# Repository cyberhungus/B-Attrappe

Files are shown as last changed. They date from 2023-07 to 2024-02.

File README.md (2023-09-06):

# B-Attrappe
## Brief
Software for a combined timing- and media playback device used in an Escape Room. All following documentation is written in German. 

## Funktionsübersicht

Die Spielleitung kann mit einem Drehimpulsgeber zwischen 3 Spielzeiten wählen. 

Hierfür wird ein Menü auf dem OLED angezeigt. 

Das Symbol ">" zeigt an, welche Zeit ausgewählt ist. 

Mit dem Knopf des Drehimpulsgebers wird das Spiel gestartet. 

Alternativ kann das Spiel mit dem Intro-Knopf gestartet werden. 

Dieser erlaubt den Teilnehmenden weiterhin, jederzeit eine Intro-Nachricht mit dem DFplayer abzuspielen. 

Wird das Spiel gestartet, zeigt der OLED die verbleibende Spielzeit an. 

Während des Spiels kann mit dem Drehimpulsgeber die Lautstärke des DFplayer manipuliert werden.

Die Teilnehmenden müssen herausfinden, welches der vier Kabel zertrennt werden muss, um das Gerät zu entschärfen. 

Wird das korrekte Kabel gekappt, wird eine Gratulationsnachricht abgespielt. 

Läuft die Zeit ab, oder wird das falsche Kabel gekappt, wird ein Explosionsgeräusch abgespielt.

Wenn das Spiel gewonnen oder verloren wird, kann das Gerät mit den Knöpfen (Intro oder Encoder) resettet werden. 

Das Gerät prüft vor Spielstart, ob alle Kabel korrekt verbunden sind - ansonsten wird das Spiel nicht gestartet, um Fehlern vorzubeugen. 

## Vorbereitung 
Alle Kabel vom rechten grünen Schraubterminal müssen mit dem linken grünen Schraubterminal verbunden werden. 

Andernfalls wird der Start des Timers verhindert. 

Die Reihenfolge der Verbindungen links ist hierbei unerheblich. 

Das äußere rechte Schraubterminal (Siehe Platinenübersicht in diesem Dokument) ist für das Deaktivierungskabel vorgesehen. 

An dieser Stelle sollte ein zum Spielfluss passendes Kabel (BLAU) verwendet werden. 

Die Farbgebung der anderen Kabel kann nach Gutdünken erfolgen.

Die Mikro-SD Karte muss präpariert werden, indem drei Ordner mit den Namen "01", "02", "03" erstellt werden. 

In diesen Ordnern ist jeweils eine Datei im mp3-Format abzuspeichern. 

Diese muss den Dateinamen "0001.mp3" erhalten. 

#### Achtung: Wird zur Vorbereitung der SD-Karte ein MAC oder Linux Computer benutzt, sind eventuell zusätzliche Schritte zu befolgen. Diese sind der DFPlayer-Dokumentation zu enehmen. Wir empfehlen die Verwendung eines Windows-Systems!

Der Abspielzeitpunkt der MP3-Dateien ist der folgenden Tabelle zu entnehmen. 

| Ordner | Abspielzeitpunkt |
|---|---|
| 01 | Intro |
| 02 | Game Over |
| 03 | Game Won |

## Verwendete Komponenten

| Komponente | Anzahl | Funktion | Optional? |
|---|---|---|---|
| Arduino Nano | 1 | Microcontroller (es können andere Microcontroller verwendet werden) | |
| DFPlayer Mini | 1 | Spielt MP3 von SD-Karte | |
| Drehimpulsgeber mit Button | 1 | User Input (versch. Funktionen) | |
| OLED-Screen 128x64 | 1 | User Output | |
| Knopf (Vandalismustaster) | 1 | Intro abspielen | |
| 1k Resistor | 2 | Noise reduzieren | |
| Dupont Pinheader 1x5 - male | 1 | Verbinden des Drehimpulsgebers | x |
| Dupont Pinheader 1x4 - male | 1 | Verbinden des OLED-Screens | x |
| Dupont Pinheader 1x2 - male | 2 | Verbinden des Introbuttons, Verbinden des Lautsprechers | x |
| Dupont Pinheader 1x8 - female | 2 | Verbinden des DFPlayer | x |
| Lochrasterplatine | 1 | Hält andere Komponenten | x |
| Schraubterminals 5.08mm Grün 1x2er | 4 | Verbinden der zerschneidbaren Kabel - zu 2x4er zusammenstecken | x |
| Micro SD-Karte | 1 | Enthält Dateien zum Abspielen mit DFPlayer - Größe egal, muss nur 3 MP3s halten | |
| Lautsprecher | 1 | Macht Geräusche | |
## Verbindungen Arduino

| Pin Arduino Nano  | Pin andere Komponente | Notizen |
|---|---|---|
| 5V | OLED-Pinheader (OLED-VCC) | |
| 5V | Drehimpulsgeber Pinheader (Drehimpulsgeber +) | |
| 5V | DFPlayer VCC | |
| GND | OLED-Pinheader (OLED-GND) | |
| GND | Drehimpulsgeber Pinheader (Drehimpulsgeber GND) | |
| GND | Introbutton Pinheader | (Polarität egal) |
| GND | Kabel Schraubterminal Links | |
| GND | DFPlayer GND | |
| A4 | OLED-Pinheader (SDA) | Hardware i2c - nicht änderbar |
| A5 | OLED-Pinheader (SCL) | Hardware i2c - nicht änderbar |
| D11 | DFPlayer RX (via 1k Resistor) | 1k Resistor unterdrückt Noise |
| D12 | DFPlayer TX (via 1k Resistor) | 1k Resistor unterdrückt Noise |
| D10 | Drehimpulsgeber Pinheader (Drehimpulsgeber SW)  | Button des Impulsgebers |
| D2 | Drehimpulsgeber Pinheader (Drehimpulsgeber CLK) | D2 unterstützt Interrupts - nicht ändern |
| D3 | Drehimpulsgeber Pinheader (Drehimpulsgeber DT)  | D3 unterstützt Interrupts - nicht ändern |
| D5 | Introbutton Pinheader | Eingang des Introbuttons (Polarität egal) |
| D9, D8, D7 | Kabel Schraubterminal Rechts | Eingänge für falsche Kabel |
| D6 | Kabel Schraubterminal Rechts | Eingang Deaktivierungskabel |

## Andere Verbindungen

| Verbindung A | Verbindung B | Notiz |
|---|---|---|
| DFPlayer SPK_1 | Pinheader Lautsprecher | Bei Lautsprecher ist Polarität egal |
| DFPlayer SPK_2 | Pinheader Lautsprecher | Bei Lautsprecher ist Polarität egal |

## Ablaufplan


## Platinenübersicht


## Platinenübersicht Alternativ

Die 2 gebauten Platinen weichen leicht voneinander ab. 
Dies ist die Übersicht der kleineren Platine.
Durch einen Lötfehler sind hier Pin 11 und 12 vertauscht. 



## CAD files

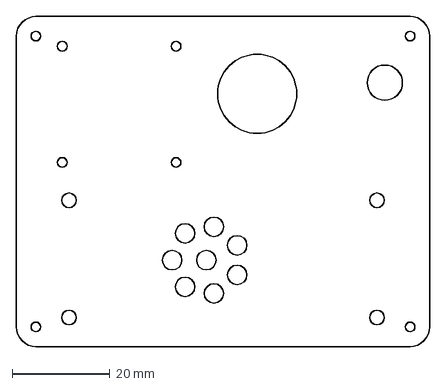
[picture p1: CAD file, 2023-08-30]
Battrappe Laser Glass.dxf
84.6 x 67.6 mm

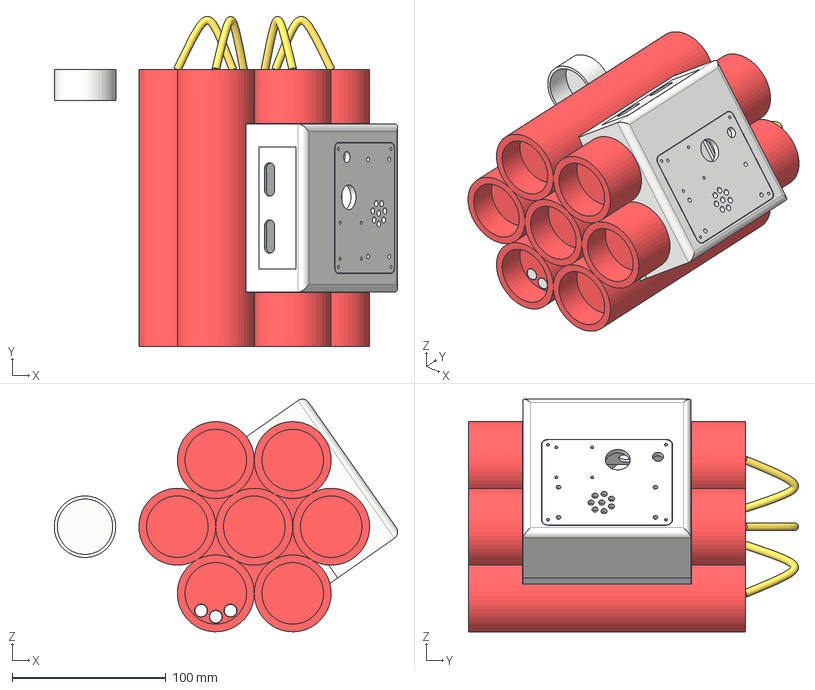
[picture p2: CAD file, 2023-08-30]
Battrappe v7.step
223.2 x 214.4 x 151.2 mm
Nobel
Lower
Midle
GlassFront
LowerLid
Cabel
SteelRod
CenterPlug
BlindPlug

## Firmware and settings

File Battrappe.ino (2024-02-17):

//Libraries für OLED
#include <SPI.h>
#include <Wire.h>

//library für dfplayer mini
#include "Arduino.h"
#include "SoftwareSerial.h"
#include "DFRobotDFPlayerMini.h"
#include <U8g2lib.h>

//erstelle dfplayer objekt und softwareSerial
SoftwareSerial mySoftwareSerial(11,12  ); // RX, TX
DFRobotDFPlayerMini myDFPlayer;
void printDetail(uint8_t type, int value);

//Pin zum auslesen des EncoderButtons
const int encoderButtonPin = 10;
//Pin zum auslesen des EncoderButtons
const int introButtonPin = 5;
// Rotary Encoder Inputs
const int CLK = 2;
const int DT  = 3;

//variablen für den Encoder
int counter = 0;
int currentStateCLK;
int lastStateCLK;

//fake kabel pins
int fakeCables[] = {9, 8, 7};
int fakeCablesLength = 3;
//deaktivierungskabel pins
int deactivateCable = 6;


//welche Minutenwerte stehen zur auswahl?
int minuteValues[] = {30, 45, 60, 1};
//Wie viele minutenwerte sind es?
int minuteValuesLength = 4;
//welcher minutenwert ist gerade ausgewählt?
int currentSelection = 0;
//wurde der timer gestartet?
bool timerStarted = false;
//wenn der timer gestartet wurde enthalt diese variable die endzeit. in millisekunden
long endTime = 0 ;

//ist das spiel gewonnen oder verloren
bool gameOverState = false;
bool gameWonState = false;
//hält die volume
int vol = 30;
//wurde die Vol vor kurzem verändert, soll ein spezieller screen gezeigt werden
bool volChanged = false;
// wann endet die anzeige der time anzeige
long volChangeEnd;
//wie lange wird die volchange message gezeigt
int volChangeDur = 1500;

//instanziiere objekt für display
U8G2_SSD1306_128X64_NONAME_1_SW_I2C u8g2(U8G2_R0, /* clock=*/ SCL, /* data=*/ SDA, /* reset=*/ U8X8_PIN_NONE);   // All Boards without Reset of the Display





//wenn alle kabel korrekt verbunden sind, ist cablestate true, sonst false
bool cableState = true;


void setup() {

  Serial.begin(115200);
  Serial.println("B-Attrappe von MM 2023");

  u8g2.begin();

  pinMode(encoderButtonPin, INPUT_PULLUP);
  pinMode(introButtonPin, INPUT_PULLUP);

  for (int i = 0; i < fakeCablesLength; i++) {
    pinMode(fakeCables[i], INPUT_PULLUP);
  }
  pinMode(deactivateCable, INPUT_PULLUP);


  pinMode(CLK, INPUT);
  pinMode(DT, INPUT);
  lastStateCLK = digitalRead(CLK);

  attachInterrupt(digitalPinToInterrupt(2), updateEncoder, CHANGE);
  attachInterrupt(digitalPinToInterrupt(3), updateEncoder, CHANGE);

  //starte softwareserial und dfplayer
  mySoftwareSerial.begin(9600);
  if (!myDFPlayer.begin(mySoftwareSerial)) {
    //halte system an wenn dfplayer nicht findbar
    Serial.println("DFPLAYER error");
    //zeige infos dazu auf dem screen
    showDFPlayerError();
    while (1);
  }
  Serial.println(F("DFPlayer Mini online."));

  myDFPlayer.volume(vol);





}
long oldPosition  = -999;

void loop() {
  //zeige sachen auf dem Display an
  readButtons();

  //Prüfe werte des Drehimpulsgebers
  readEncoder();
  //schaue ob ein knopf gedrückt wurde
  readButtons();
  //gucke, welche zeitbasierten funktionen
  checkTimes();
  //prüfe ob die kabel durchgeschnitten wurden
  checkCables();
  readButtons();
    //Prüfe werte des Drehimpulsgebers
  readEncoder();
  u8g2.firstPage();
  do {
    showDisplay();
  } while (u8g2.nextPage());
  readButtons();
    //Prüfe werte des Drehimpulsgebers
  readEncoder();

}

//guckt ob alle kabel verbunden sind bzw welche kabel nicht verbunden sind
void checkCables () {

  //Cablestate wird true oder false, je nachdem ob alle kabel verbunden sind
  //wir machen das hier, damit das hauptmenü anzeigen kann ob das system bereit ist
  cableState = allCablesConnected();

  int cableres;
  //checke jedes fake kabel
  for (int i = 0; i < fakeCablesLength; i++) {
    //lese den pin
    cableres = digitalRead(fakeCables[i]);
    //wenn fake-kabel durchtrennt dann game over
    if (cableres == HIGH) {
      if (timerStarted) {
        gameOver();
        Serial.println("Fake cable severed");

      }
    }
  }
  //checke deaktivierungskabel
  cableres = digitalRead(deactivateCable);
  //wenn deaktivierungskabel getrennt dann gewonnen
  if (cableres == HIGH) {
    if (timerStarted) {
      gameWon();
      Serial.println("Correct cable severed");

    }
  }

}

//gibt wahr zurück, wenn alle kabel verbunden sind
//gibt falsch zurück, wenn nicht alle kabel verbunden
bool allCablesConnected() {
  int checksum = 0;
  int result = 0;
  //checke jedes fake kabel
  for (int i = 0; i < fakeCablesLength; i++) {
    //lese den pin
    result = digitalRead(fakeCables[i]);

    Serial.print("Fake at: ");
    Serial.print(fakeCables[i]);
    Serial.print(" - ");
    Serial.println(result);
    if (result == HIGH) {
      
        checksum++;
      
    }
  }
  //checke deaktivierungskabel
  result = digitalRead(deactivateCable);
  Serial.print("Real  at: ");
  Serial.print(deactivateCable);
  Serial.print(" - ");
  Serial.println(result);
  if (result == HIGH) {
    
      checksum++;
    
  }
  if (checksum != 0) {

    return false;
  }
  else {
    return true;
  }
}



void readEncoder() {

  //leseEncoder
  long newPosition = counter;

  //wenn position anders.
  if (newPosition != oldPosition) {
    //wenn kleiner als letze
    if (newPosition < oldPosition) {
      Serial.println("Kleiner");
      //wenn timer gestarted inkrementiere currentselection - wählt menüitems aus
      if (!timerStarted) {
        currentSelection++;
      }
      //wenn timer schon gestartet kann der encoder als lautstärkeregler verwendet werden
 
    }
    //wenn position größer als letze
    else if (newPosition > oldPosition) {
      Serial.println("grosser");
      //wenn timer gestartet dekrementiere currentselection - wählt menüitems aus
      if (!timerStarted) {
        currentSelection--;
      }
      //veringere Lautstärke

    }
  }
  //limitiere werte die currentselection annehmen kann
  if (currentSelection < 0) {
    currentSelection = minuteValuesLength - 1;
  }
  else if (currentSelection >= minuteValuesLength) {
    currentSelection = 0;
  }
  oldPosition = newPosition;
}

//prüft verschiedene Zeiten
void checkTimes() {
  //als erstes die zeit holen - wir wollen millis nicht immer wieder abrufen
  long current = millis();
  //nur wenn spiel nicht vorüber
  if (!gameWonState && !gameOverState) {
    //wenn timer gestarted, prüfe ob zeit abgelaufen
    if (timerStarted) {
      //wenn zeit jetzt größer als endzeit dann ist game over
      if (current > endTime) {
        Serial.println("Zeit abgelaufen!");
        gameOver();
      }
    }
  }

  if (volChanged) {
    if (current > volChangeEnd) {
      Serial.println("Ende der Volume Anzeige");
      volChanged = false;

    }


  }
}
//erhöht lautstärke
void increaseVol() {
  if (vol < 30) {

    vol++;
    myDFPlayer.volume(vol);
    volChanged = true;
    volChangeEnd = millis() + volChangeDur;
    Serial.print("Lautstarke geandert: " );
    Serial.println(vol);

  }
}
//verringert lautstärke
void decreaseVol() {
  if (vol > 5) {
    vol--;
    myDFPlayer.volume(vol);
    volChanged = true;
    volChangeEnd = millis() + volChangeDur;
    Serial.print("Lautstarke geandert: " );
    Serial.println(vol);
  }
}

//aufgerufen wenn falsches kabel getrennt oder zeit abgelaufen
void gameOver() {
  if (!gameOverState && !gameWonState) {
    //  fillcircle();
    gameOverState = true;
    playBoom();
    Serial.println("game over");
  }
}
//aufgerufen wenn korrektes kabel getrennt
void gameWon() {
  if (!gameOverState && !gameWonState) {
    gameWonState = true;
    playFanfare();
    Serial.println("game won");
  }
}

//diese funktion reagiert auf drücken des encoders oder des intro buttons
void readButtons() {
  //Intro Button Result
  int introRes = digitalRead(introButtonPin);

  //encoder Button result
  int encRes = digitalRead(encoderButtonPin);
  long timestamp = millis();

  //    Serial.print("EncoderButton:");
  //    Serial.println(encRes);
  //      Serial.print("Intro:");
  //    Serial.println(introRes);
  if (!gameOverState && !gameWonState) {

    //nur button eingaben akkzeptieren wenn wenn timer gestartet und alle Kabel korrekt verbunden
    if (!timerStarted && cableState) {
      //eingabe zum timer start mit dem encoder-knopf
      if (encRes == LOW) {
        showIntroInfo();
        delay(10);
        playIntro();
        delay(35000);
        playCountdown();
        delay(2000);
        timerStarted = true;
        timestamp = millis();
        endTime = timestamp + (minuteValues[currentSelection] * 60000);
        Serial.print("Timer gestartet um: ");
        Serial.print(timestamp);
        Serial.print(". Timer gestartet mit: ");
        Serial.print( minuteValues[currentSelection] );
        Serial.print("Ende: ");
        Serial.println(endTime);

      }
      //eingabe zum timer start mit dem Intro knopf
      if (introRes == LOW) {
        showIntroInfo();
        delay(10);
        playIntro();
        delay(35000);
        playCountdown();
        delay(2000);
        timestamp = millis();
        timerStarted = true;
        endTime = timestamp + (minuteValues[currentSelection] * 60000);
        Serial.print("Timer + Intro abspielen gestartet um: ");
        Serial.print(timestamp);


      }
    }
    else if (timerStarted) {
      //wenn timer schon läuft spielt der intro knopf nur das intro
      if (introRes == LOW) {
        Serial.print(" Intro abspielen gestartet um: ");
        Serial.print(timestamp);
        Serial.print("Ende: ");
        Serial.println(endTime);
        playIntro();
      }
    }
  }
  //wenn gameover oder gamewon resetten wir die variablen dafür, und somit das system
  else {
    if (encRes == LOW) {
      gameOverState = false;
      gameWonState = false;
      timerStarted = false;
      Serial.println("reset");
      showReset();
      delay(2000);
    }

    if (introRes == LOW) {

      gameOverState = false;
      gameWonState = false;
      timerStarted = false;
      Serial.println("reset");
      showReset();
      delay(2000);
    }
  }
}

//diese funktion regelt die anzeige auf dem Bildschirm
void showDisplay() {
  //zeige splashscreen wenn system gestartet wird
  if (millis() < 3000) {
    showSplash();
  } else {
    //wenn das spiel nicht im gamover oder gewon zustand ist
    if (!gameOverState && !gameWonState) {
      //wenn der timer nicht gestartet ist, zeige hauptmenü
      if (!timerStarted) {
        //zeichne minutenwert optionen
        for (int i = 0; i < minuteValuesLength; i++) {

          u8g2.setFont(u8g2_font_ncenB10_tr);
          u8g2.setCursor(10, 20 + (i * 15));
          u8g2.print(minuteValues[i]);

        }
        //zeichne auswahlpfeil an der richtigen position, basierend auf der currentselection variabel
        u8g2.setCursor(0, 20 + ( currentSelection * 15));
        u8g2.print(">");

        //zeige an, ob die Kabel korrekt verbunden sind
        if (!cableState) {
          u8g2.setFont(u8g2_font_5x7_tr);

          u8g2.setCursor(40, 60 );
          u8g2.print("KABELFEHLER");
        }
        else {
          u8g2.setFont(u8g2_font_5x7_tr);

          u8g2.setCursor(40, 60 );
          u8g2.print("KABEL OKAY");
        }

      }
      //wenn der timer gestartet wurde, zeige die verbleibende zeit an
      else {
        if (!volChanged) {
          long remTime = endTime - millis();
          long remMinutes = remTime / 60000;
          long remSeconds = remTime / 1000 % 60;
          u8g2.setFont(u8g2_font_7Segments_26x42_mn);
          u8g2.setCursor(0, 42);
          u8g2.print(remMinutes);
          u8g2.setCursor(58, 42);
          u8g2.print(":");
          u8g2.setCursor(70, 42);
          u8g2.print(remSeconds);
        }
        //es sei denn, die lautstärke wurde kürzlich geändert: dann zeige lautstärke an
        else {
          u8g2.setFont(u8g2_font_ncenB10_tr);
          u8g2.drawStr(0, 20 ,  "VOL");
          u8g2.drawStr(64, 20 ,  String(vol).c_str());
        }
      }
    }
    //folgender Code zeigt informationen an, wenn spiel gewonnen oder verloren
    else if (gameOverState && !gameWonState) {
      u8g2.setFont(u8g2_font_ncenB10_tr);
      u8g2.drawStr(0, 30 , "Game Over");
      u8g2.setFont(u8g2_font_5x7_tr);
      u8g2.drawStr(0, 50 , "Knopf zum Reset ");
    }
    else if (gameWonState && !gameOverState) {
      u8g2.setFont(u8g2_font_ncenB10_tr);
      u8g2.drawStr(0, 20 , "GEWONNEN!");
      u8g2.setFont(u8g2_font_5x7_tr);
      u8g2.drawStr(0, 40 , "Saubere Arbeit!  ");
      u8g2.drawStr(0, 60 , "Knopf zum Reset ");
    }
    //wenn spiel gleichzeitig gewonnen und verloren ist, zeige ERROR an
    else if (gameWonState && gameOverState) {
      u8g2.setFont(u8g2_font_ncenB10_tr);
      u8g2.drawStr(0, 30 , "ERROR");
      u8g2.setFont(u8g2_font_5x7_tr);
      u8g2.drawStr(0, 50 , "Knopf zum Reset ");
    }





  }
}

//playfunktionen kapseln das abspielen bestimmter tracks auf dem DFPlayer
void playIntro() {
  myDFPlayer.playFolder(01, 01);
}
void playBoom() {
  myDFPlayer.playFolder(02, 01);
}
void playFanfare() {
  myDFPlayer.playFolder(03, 01);
}
void playCountdown() {
  myDFPlayer.playFolder(04, 01);
}

//diese funktion wird als callback aufgerufen, wenn der drehimpulsgeber bewegt wird
//sie regelt die interne logik des encoders
void updateEncoder() {
  // Read the current state of CLK
  currentStateCLK = digitalRead(CLK);

  // If last and current state of CLK are different, then pulse occurred
  // React to only 1 state change to avoid double count
  if (currentStateCLK != lastStateCLK  && currentStateCLK == 1) {

    // If the DT state is different than the CLK state then
    // the encoder is rotating CCW so decrement
    if (digitalRead(DT) != currentStateCLK) {
      counter --;

    } else {
      // Encoder is rotating CW so increment
      counter ++;

    }


    // Serial.print(" | Counter: ");
    //Serial.println(counter);
  }

  // Remember last CLK state
  lastStateCLK = currentStateCLK;
}
void showIntroInfo() {

  u8g2.setFont(u8g2_font_ncenB10_tr);
  u8g2.drawStr(0, 24, "Intro spielt!");
  u8g2.drawStr(0, 48, "Bitte warten!");
}
void showSplash() {

  u8g2.setFont(u8g2_font_ncenB10_tr);
  u8g2.drawStr(0, 24, "Bomb!");
  u8g2.drawStr(0, 48, "MM 2023");

}
void showReset() {

  u8g2.setFont(u8g2_font_ncenB10_tr);
  u8g2.drawStr(0, 24, "RESET!");
  u8g2.drawStr(0, 48, "MM 2023");
}

void showDFPlayerError() {
  u8g2.firstPage();
  do {
    u8g2.setFont(u8g2_font_ncenB10_tr);
    u8g2.drawStr(0, 20 , "ERROR");
    u8g2.setFont(u8g2_font_5x7_tr);
    u8g2.drawStr(0, 30 , "DFPlayer-Problem ");
    u8g2.drawStr(0, 50 , "Checke SDCard");
  } while (u8g2.nextPage());

}

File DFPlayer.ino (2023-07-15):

void printDetail(uint8_t type, int value) {
  switch (type) {
    case TimeOut:
      Serial.println(F("Time Out!"));
      break;
    case WrongStack:
      Serial.println(F("Stack Wrong!"));
      break;
    case DFPlayerCardInserted:
      Serial.println(F("Card Inserted!"));
      break;
    case DFPlayerCardRemoved:
      Serial.println(F("Card Removed!"));
      break;
    case DFPlayerCardOnline:
      Serial.println(F("Card Online!"));
      break;
    case DFPlayerUSBInserted:
      Serial.println("USB Inserted!");
      break;
    case DFPlayerUSBRemoved:
      Serial.println("USB Removed!");
      break;
    case DFPlayerPlayFinished:
      Serial.print(F("Number:"));
      Serial.print(value);
      Serial.println(F(" Play Finished!"));
      break;
    case DFPlayerError:
      Serial.print(F("DFPlayerError:"));
      switch (value) {
        case Busy:
          Serial.println(F("Card not found"));
          break;
        case Sleeping:
          Serial.println(F("Sleeping"));
          break;
        case SerialWrongStack:
          Serial.println(F("Get Wrong Stack"));
          break;
        case CheckSumNotMatch:
          Serial.println(F("Check Sum Not Match"));
          break;
        case FileIndexOut:
          Serial.println(F("File Index Out of Bound"));
          break;
        case FileMismatch:
          Serial.println(F("Cannot Find File"));
          break;
        case Advertise:
          Serial.println(F("In Advertise"));
          break;
        default:
          break;
      }
      break;
    default:
      break;
  }

}

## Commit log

2023-08-30 added laser dxf file and step file
    [Battrappe Laser Glass.dxf]
2024-02-17 Rework 2
    removed audio volume being changed. fixed cable detection bug, fixed bug with button
    [Battrappe.ino]
